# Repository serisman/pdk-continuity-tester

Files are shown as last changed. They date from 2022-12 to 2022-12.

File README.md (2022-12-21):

# pdk-continuity-tester
A simple standalone continuity tester, based on the ultra-inexpensive (~$0.03) Padauk microcontroller and a piezo buzzer.
- Turns on a Piezo Buzzer when there is continuity detected between the Probe pin and GND.
- Uses the Comparator to test for continuity (i.e. Reference(+) > Probe(-)).
- Goes to sleep after a short duration of inactivity to save battery power (< 0.5 uA).
- Optional LED indicates device is powered on and not sleeping.

This is a port of, and based on an original project for the ATtiny85(V) by David Johnson-Davies:
- http://www.technoblogy.com/show?1YON
- https://github.com/technoblogy/continuity-tester

### Links
- [Firmware](firmware/)
- [PCB](pcb-s08/)

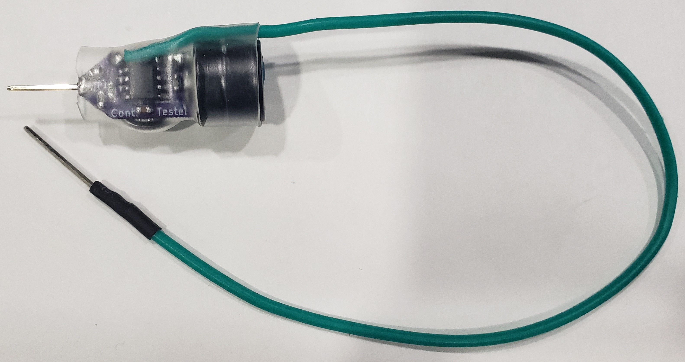
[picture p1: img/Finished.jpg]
Finished

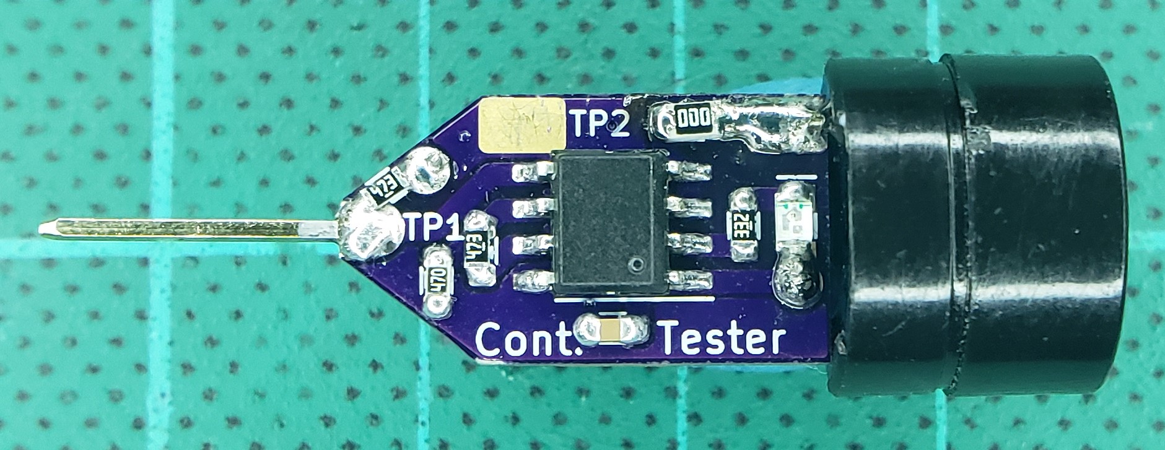
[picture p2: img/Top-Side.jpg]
Top Side

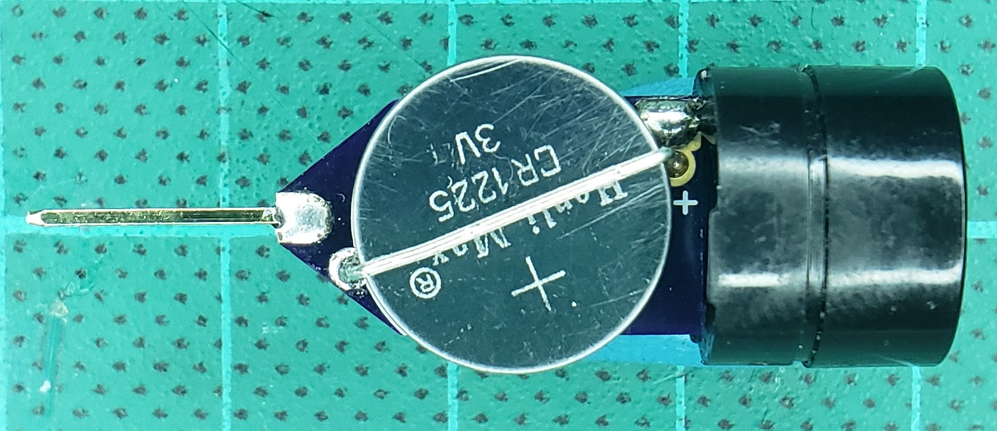
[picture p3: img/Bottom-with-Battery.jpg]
Bottom Side


### Hardware Circuit

##### Schematic
(for 8-pin PFS154, PFS173, PMS150C/PMS15A, PMS152, PMS154C, PMS171B)
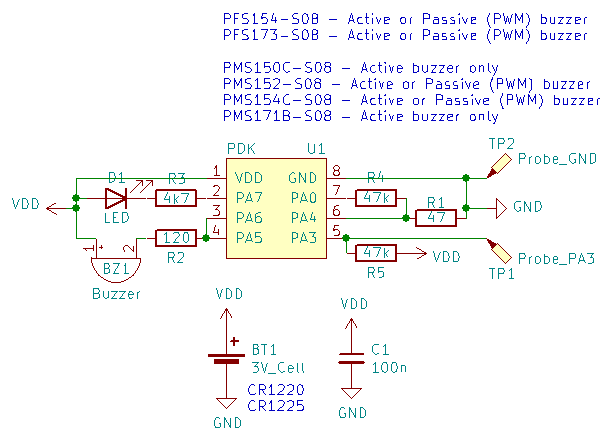
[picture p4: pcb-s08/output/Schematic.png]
Schematic


**Probe/Reference**:

One lead of the Probe is connected to one of the Comparator (-) pins, and the other lead is connected to GND. 
- The Probe lead is placed on the PA3 pin (Port A, Bit 3).

The Reference uses the Comparator (+) pin, with a 47 ohm resistor to GND.
- The Reference is placed on the PA4 pin (Port A, Bit 4). 

**Buzzer**:

The Buzzer is placed on the PA5 pin (Port A, Bit 5).  It is also connected to the PA6 pin, but the current firmware doesn't use this (yet).

For devices with an 11-bit PWM (i.e. PFS154, PFS173, PMS152, PMS154C), PA5 is also one of the PWM pins, enabling PWM control of the Buzzer's frequency using a Passive buzzer.

For other devices (i.e. PMS150C/PMS15A, PMS171B), the Buzzer can only be turned on/off and an Active buzzer is required.

In either case the Buzzer is used with a current sink configuration.

This means that one side of the Buzzer is connected to VDD, and the other is connected (through a current limiting resistor) to the digital pin of the IC.
- To enable the Buzzer (Passive / PWM), it is driven with an inverted 50% duty cycle at approx 2kHz.
- To enable the Buzzer (Active), it is driven LOW, meaning current will flow.
- To disable the Buzzer, it is floated HIGH, meaning no current will flow.

**LED**:

The LED is placed on the PA7 pin (Port A, Bit 7) with a current sink configuration.

This means the negative leg (or cathode) of the LED is connected to the digital pin of the IC, and the positive leg (or anode) of the LED is connected through a current limiting resistor to VDD.
- When the digital pin is LOW, current will flow through the LED and it will light up.
- When the digital pin is HIGH, no current will flow and the LED will turn off.

### Compatibility
This project is currently intended to be run (without modifications) on the PFS154, PFS173, PMS150C/PMS15A, PMS152, PMS154C, and PMS171B Padauk microcontrollers,
but it should be able to be modified to run on just about every currently known Padauk microcontroller that is supported by SDCC and the Easy PDK Programmer.
Some microcontrollers will require additional definitions in the [firmware/hal.h](firmware/hal.h) file,
and less common devices may require additional device specific include files (firmware/pdk/device/*.h) to be supplied.

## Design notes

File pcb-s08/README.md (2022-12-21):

# pcb-s08 ([pdk-continuity-tester](https://github.com/serisman/pdk-continuity-tester/))

### Schematic
(for 8-pin PFS154, PFS173, PMS150C, PMS15A, PMS152, PMS154C, PMS171B)
Schematic

### PCB

This PCB design was created with KiCad, and has been [shared on OSHPARK](https://oshpark.com/shared_projects/1CFwpMAd).
There are also gerber files available in the [output/gerber/](output/gerber/) directory, or [gerber.zip](output/gerber.zip).

Attach a ~12mm Piezo Buzzer to the end. PMS150C, PMS15A, and PMS171B require an Active (on/off) buzzer.  PFS154, PFS173, PMS152, and PMS154C use a Passive (PWM) buzzer.

Attach a CR1225 (or CR1220, CR1025, CR927, etc...) to the bottom after soldering a wire to hold it (and act as the positive contact).

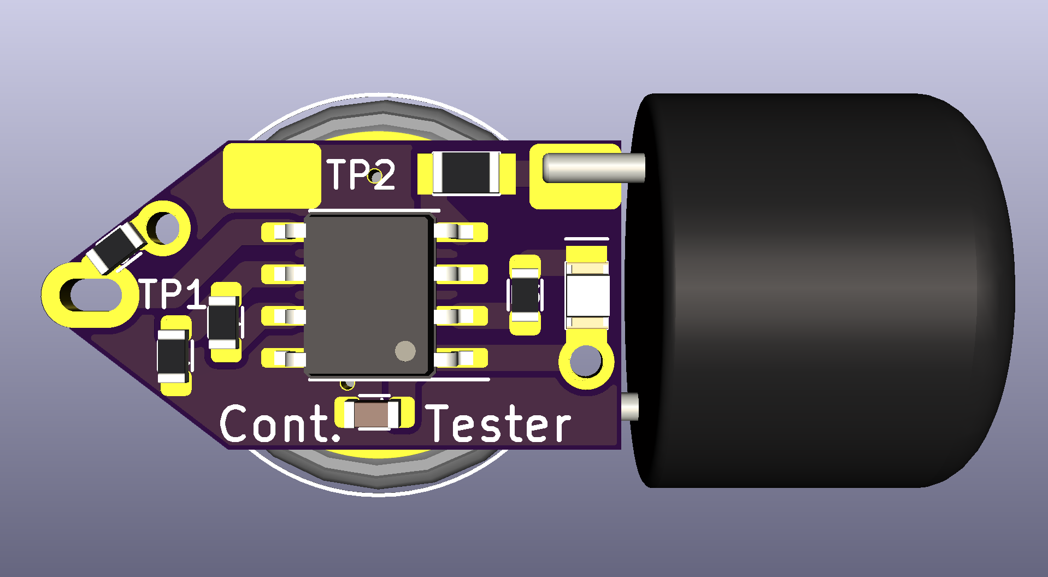
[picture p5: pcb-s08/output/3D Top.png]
3D Top

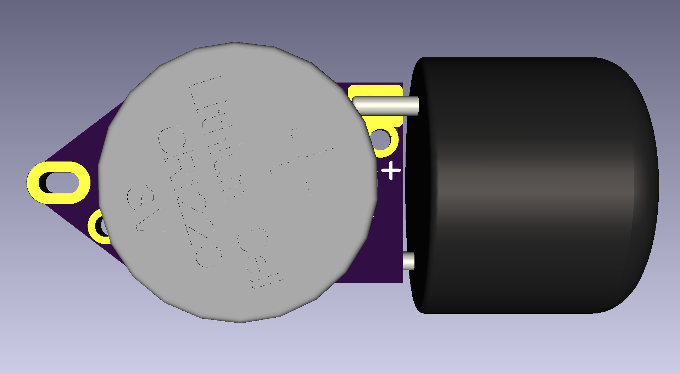
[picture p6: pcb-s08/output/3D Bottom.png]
3D Bottom


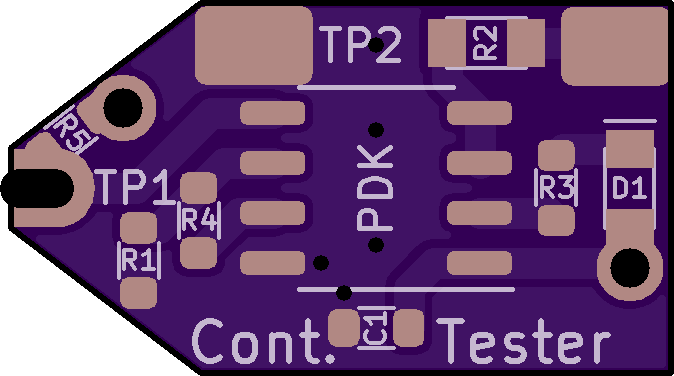
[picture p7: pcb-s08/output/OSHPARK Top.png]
PCB Top

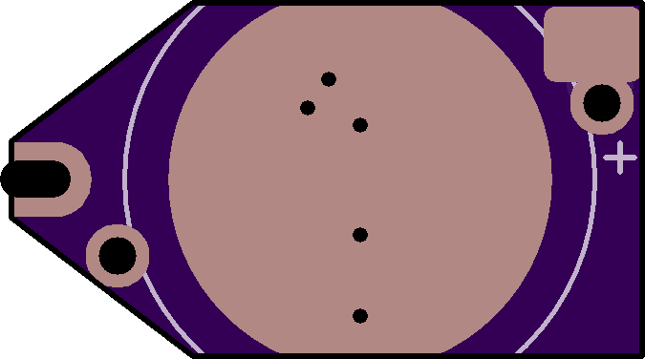
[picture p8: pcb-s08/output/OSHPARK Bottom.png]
PCB Bottom


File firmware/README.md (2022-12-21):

# firmware ([pdk-continuity-tester](https://github.com/serisman/pdk-continuity-tester/))

### Toolchain:
- The open-source [Small Device C Compiler (SDCC)](http://sdcc.sourceforge.net/)
  - Requires version 3.9.0 or newer - version 4.0.0+ preferred
- The open-source [Easy PDK Programmer](https://github.com/free-pdk/easy-pdk-programmer-software)
  - Requires version 1.3 or newer
- The open-source [pdk-includes](https://github.com/free-pdk/pdk-includes) repository
  - Integrated via local copy into the pdk/ directory
- The open-source [easy-pdk-includes](https://github.com/free-pdk/easy-pdk-includes) repository
  - Integrated via local copy into the easy-pdk/ directory
- Also requires 'make' and other common build tools

### Build Commands:
```
make clean
make build
make size (also calls build)
make program (also calls size which calls build)
```
> Note: These commands can be chained as well.  i.e. `make clean program`

### Customization:
Edit the variables at the top of the Makefile to:
- **DEVICE**: Use a different Padauk MCU (defaults to PFS154)
- **TARGET_VDD_MV**: Use a different voltage while calibrating the internal oscillator (IHRC) (defaults to 3000mV)

> Note: Both of these variables can be changed on the commandline as well.  i.e. `make DEVICE=PFS173 clean program` 

### Compatibility
This project is currently intended to be run (without modifications) on the PFS154, PFS173, PMS150C/PMS15A, PMS152, PMS154C, and PMS171B Padauk microcontrollers,
but it should be able to be modified to run on just about every currently known Padauk microcontroller that is supported by SDCC and the Easy PDK Programmer.
Some microcontrollers will require additional definitions in the [hal.h](hal.h) file,
and less common devices may require additional device specific include files (pdk/device/*.h) to be supplied.

### Build Stats
- Code Size: ~90-109 words (depending on the microcontroller)
- RAM usage: 2 bytes + stack

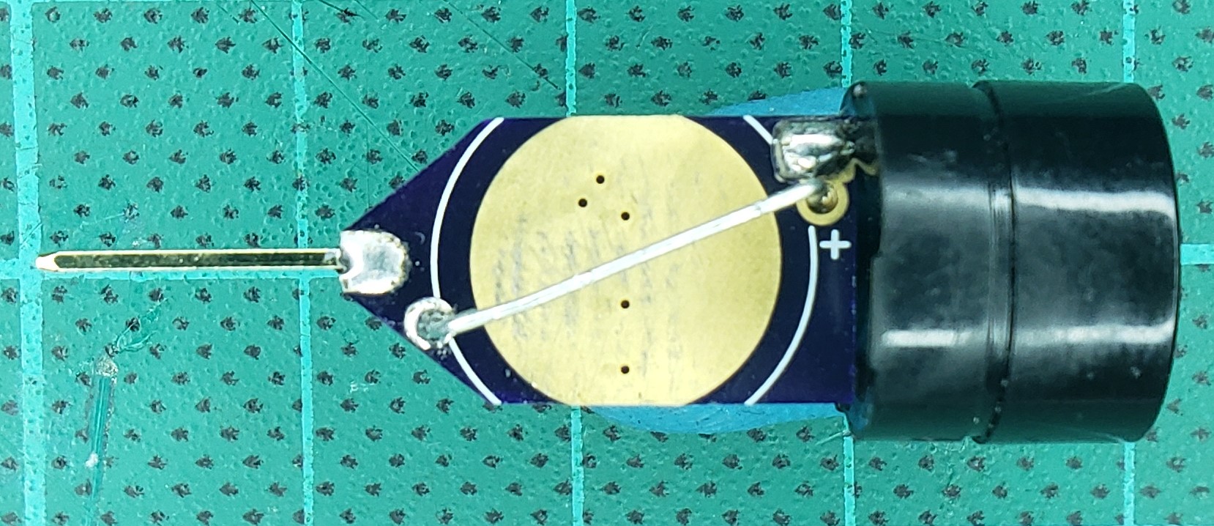
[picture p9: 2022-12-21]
img/Bottom-Side.jpg

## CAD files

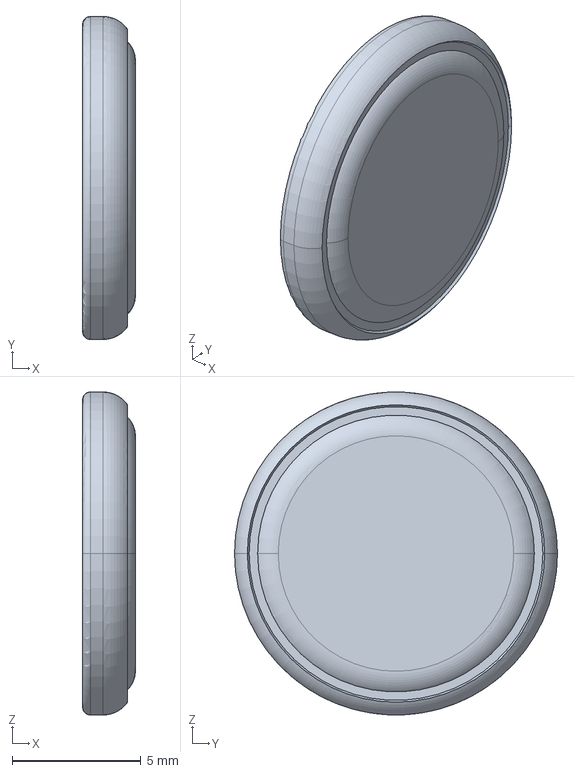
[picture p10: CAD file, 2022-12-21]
pcb-s08/modules/cr1220.step
2.05 x 12.6 x 12.5 mm

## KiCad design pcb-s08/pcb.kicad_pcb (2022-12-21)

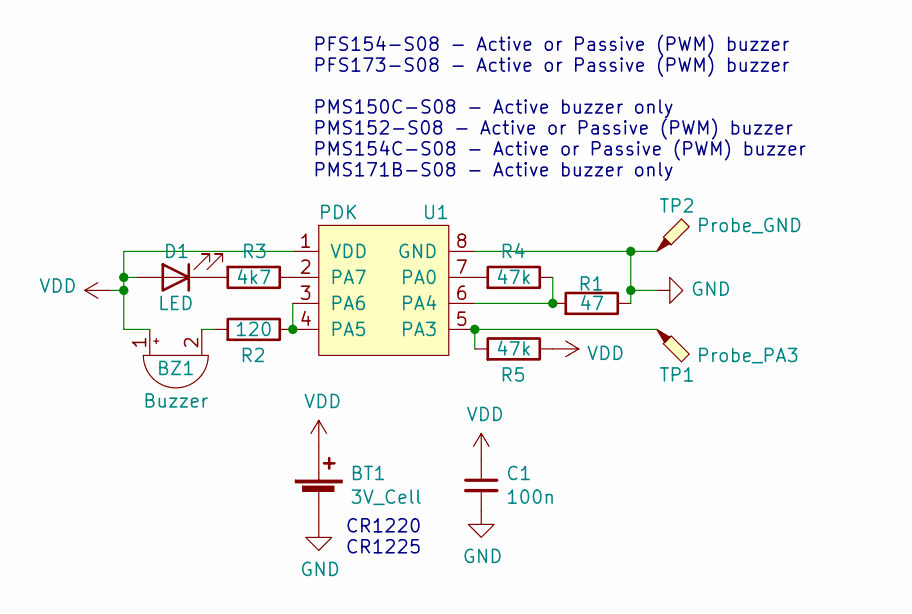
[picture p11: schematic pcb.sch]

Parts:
BT1: 3V_Cell; BatteryHolder_12mm
BZ1: Buzzer; Buzzer_12x9.5RM7.6
C1: 100n; C_0603
D1: LED; LED_0805
R1: 47; R_0603
R2: 120; R_0805
R3: 4k7; R_0603
R4, R5: 47k; R_0603
TP1: Probe_PA3; Pad_2.0x3.0mm
TP2: Probe_GND; Pad_2.0x3.0mm
U1: PDK; SOP-8_3.9x4.9mm_P1.27mm

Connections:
GND: BT1.2 (-), C1.2, R1.1, TP2.1, U1.8 (GND)
unnamed: BZ1.2 (+), R2.2
unnamed: D1.1 (K), R3.2
unnamed: R1.2, R4.1, U1.6 (PA4)
unnamed: R2.1, U1.3 (PA6), U1.4 (PA5)
unnamed: R3.1, U1.2 (PA7)
unnamed: R4.2, U1.7 (PA0)
unnamed: R5.2, TP1.1, U1.5 (PA3)
VDD: BT1.1 (+), BZ1.1 (-), C1.1, D1.2 (A), R5.1, U1.1 (VDD)

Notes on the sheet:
PFS154-S08 - Active or Passive (PWM) buzzer PFS173-S08 - Active or Passive (PWM) buzzer PMS150C-S08 - Active buzzer only PMS152-S08 - Active or Passive (PWM) buzzer PMS154C-S08 - Active or Passive (PWM) buzzer PMS171B-S08 - Active buzzer only
CR1220 CR1225

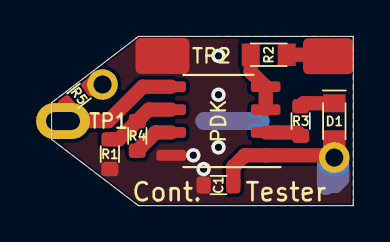
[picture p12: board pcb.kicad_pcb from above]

Board: 2 copper layers, 16.8 x 9.4 mm, 12 parts (1 on the bottom side), 9 nets.

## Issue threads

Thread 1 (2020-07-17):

Not working on PMS150C

kaweksl, 2020-07-17:
I made pcb , replaced buzzer with led since i don't have buzzers without generator
And it doesn't work,
tested also with PMS150C-S08 on breadboard and it doesn't work.
I have tested with PFS154 on breadboard and it works.

Status led is always On, after applying power there is something on buzzer for little time, but after that silence.

You have it working on PMS150C ?

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

serisman, 2020-07-17:
No, I haven't actually tested this on the PMS150C yet.  I will dig through the code and see if I can find what might be wrong.

serisman, 2020-07-17:
Well there was a typo in hal.h on line 20 that meant the wrong defines were used.  I'll push up a fix.  Maybe it was that simple?

serisman, 2020-07-17:
Ok, I can confirm that it is working properly on a 6-pin PMS150C (after the fix on line 20 of hal.h).

The only difference I found so far, is that the buzzer is operating at a much higher pitch.  I'll have to dig into the PWM values again.

kaweksl, 2020-07-17:
> Wow... you built that PCB pretty fast! I just designed the board this morning.
Design is small, uses mostly 1 layer, for that i have fast method. Photosensitive film + DLP 3D printer, 10 min. work + 1h waiting,

> The only difference I found so far, is that the buzzer is operating at a much higher pitch (about 8 kHz instead of 2 kHz). I'll have to dig into the PWM values again.

Almost works :)
Looks like pwm freq is ~8kHz but duty cycle is minimum (1 timers cycle ?)

kaweksl, 2020-07-17:
Hmm also it turns off even if probe is constantly shorted to ground.
I don't see 8kHz with 50% duty either.
Maybe pin change wakes up uC but comparator is not detecting anything and uC goes to sleep again ?.

serisman, 2020-07-17:
> Hmm also it turns off even if probe is constantly shorted to ground.
> I don't see 8kHz with 50% duty either.
> Maybe pin change wakes up uC but comparator is not detecting anything and uC goes to sleep again ?.

What voltage are you using?  I am noticing something similar on my PFS173 with anything over about 3.3V.  But, it seems correct at 3ish V.

kaweksl, 2020-07-17:
Powered with bench psu, now also tried with cr2032, same thing

serisman, 2020-07-17:
I just pushed some new code that fixes the PWM issues.  Can you give that a try?

Which IC are you currently testing with?

kaweksl, 2020-07-17:
PMS150C-u6

serisman, 2020-07-17:
Ok, weird.  I am not seeing that issue.

I just tested my PFS154 and PMW150C-U06, and they both work fine with any voltage from about 2 up to about 5.  I can hold the probes together and it will stay on until shortly after I separate them.

I do still have a weird issue with my PFS173 where it isn't working over about 3.3V, but seems to work fine between 2 up to about 3.2.  Maybe it is a bad IC, or maybe I'll have to dig through the datasheet more tomorrow to see if there is anything different about it.

FYI... signing off for the night (2:40 AM here).

kaweksl, 2020-07-17:
Shouldn't we calibrate bandgap ?

serisman, 2020-07-17:
> Shouldn't we calibrate bandgap ?

Maybe, but I don't think this actually uses the bandgap.

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

Ok, weird.  I'll have to do some additional testing with different chips myself.

> EDIT:
> Ok don't need to calibrate BG because we don't use it, maybe we should ?

Maybe.  How do you envision using it?

> I think pull-ups differ from chip to chip very much, as they are weak pmos, not resistors

Interesting.  Maybe we should try with external pull ups then.  According to the original article ~50k (i.e. 47k) would be a good value to try.

serisman, 2020-07-17:
I just tried using external 47k resistors on the Reference and Probe pins (Comp+ and Comp-), after commenting out the PAHP lines in the source code.  That seems to have fixed the weirdness I was seeing with the PFS173.

The downsides are two additional components, but more importantly, the idle power consumption increased dramatically because we have no way of turning off the external pull-up on the Reference pin (so there is always a 47k load).  I measured an idle power consumption increase from around 0.2 (+/- .1) uA up to 40-100 uA (depending on VDD).  That means a few weeks to months of idle time instead of many years.

I'll try some more tests later on when I have more free time.  Maybe higher value resistors would work just as well, and cause less idle power consumption.

serisman, 2020-07-17:
Another thought, although untested... we might be able to re-arrange the circuit a bit to pull-up the Reference and Probe lines to the 'power' LED, instead of pulling them up to VDD.  That way, no current would flow when the LED/MCU is off.  This would require changing the LED to be active high (source) instead of active low (sink).  Might still need an internal pull-up on Probe to still allow wake-up from sleep.  I'll have to think about this more.

serisman, 2020-07-17:
Did some more research and thinking on the subject, and have the additional observations:

1. The Padauk datasheets list a Comparator Offset of +/- 10-20 mV.  So there can be a fairly big difference between ICs.

2. The Padauk datasheets specify a pull-high resistance of approx 200k -> 600k (in the 3.3v -> 2v range) for the PFS154 and PMS150C chips, but only 150k -> 400k for the PFS173.  Either way, this is way higher than the ATtiny85's 20k - 50k.

3. The original circuit was build around a 50 ohm / ~50k ohm voltage divider for the reference, which means about 5mV at 5v.  We are using higher pull-ups and lower voltage, say 200k ohm and 3v, which is only 1mV reference.  Not sure how that interacts with the Comparator Offset that may be significantly more than our reference voltage.  We could increase the 50 ohm resistor to compensate, but that would mean we would trigger on higher resistances as well.  Or, we could decrease the pull-up resistor, but then we have to solve the idle power consumption issue.

kaweksl, 2020-07-18:
Sadly PA5 is open drain only :/ , Maybe it would be possible to make permanent pull-up on reference pin and switchable low resistor ?.
Or maybe swap PA6 and PA5
external pull-up on probe shouldn't take power

serisman, 2020-07-18:
> Making externally switchable pull-up might work but sadly PA5 is open drain only, and can source current only thru its pull-up :/

Yeah, I was thinking of the PFS154/PFS173 when I was thinking about that, where the LED is on PA6.  But, I agree, that won't work on the PMS150C where the LED is on PA5.

>, Maybe it would be possible to make permanent pull-up on reference pin and switchable low resistor ?.

Maybe, not sure at the moment.

> Or maybe swap PA6 and PA5. I'm not sure if PA5 have wake-up.

We can't really swap PA6/PA5, at least if we want 6-pin compatibility.  The reference has to be on the COMP+ pin which is PA4.  The probe has to be on a COMP- pin, which means PA3 for the PFS1xx, leaving only PA5 for the Buzzer which needs PWM.  That only leaves the PA6 for the LED.  For the PMS150C, the only available PWM is PA3, meaning PA6 has to be probe, and that only leaves PA5 for the LED.

> External pull-up on probe shouldn't take power while not operating.

Yeah, the probe doesn't matter.  The issue is with the Reference because it has the voltage divider that always consumes power unless you can remove one side from the equation.

serisman, 2020-07-18:
Ok, another option...

We can use the internal voltage reference, instead of creating our own.

Using GPCS, we can set VintR to a minimum of 1/32 * VDD, which means ~94 mV @ 3v.  This frees up the COMP+ pin (PA4) for other uses as well, and may mean we could now have a consistent set of pins across all devices.

To maintain a 50 ohm threshold/sensitivity, we would install an external 1.5k pull-up resistor on the probe pin, instead of using the internal pull-up.

Doing it this way solves the comparator offset/variance issues as well as the idle power consumption issues, but does have a downside that we have increased the current that passes through the probe to about ~1.875 mA.

Since most multimeters use around 1mA, it might be better to increase the sensitivity up to 100 ohm which decreases the current down to ~0.9375mA.

So, not as good as the 50 ohm / 0.1 uA of the original design, but at least as good as most multimeters.

serisman, 2022-12-21:
It's only been 2 1/2 years, but I finally picked this project back up and made a decision on how to fix the issue caused by the weak internal pull-up resistors.

After re-considering all the options, I felt that external pull-up resistors was the best of the available options.  In order to keep the low power consumption when sleeping, this means connecting one of them to an output pin (instead of directly to VDD).  This allows us to switch it off before entering sleep mode, thereby eliminating the constant drain.  This required an extra pin than the 6-pin ICs had available, so I just consolidated everything to a new single 8-pin design.

The old code/schematics/pcbs are still in a branch (old-vesion), but I don't intend to touch them further.

Closed 2022-12-21.

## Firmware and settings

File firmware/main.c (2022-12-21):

/*
  pdk-continuity-tester

  Copyright (C) 2020  serisman  <github@serisman.com>
  Based on an original project by David Johnson-Davies (http://www.technoblogy.com/show?1YON)

  Turns on a Piezo Buzzer when there is continuity detected between the Probe pin and GND.
  Uses the Comparator to test for continuity (i.e. Reference(+) > Probe(-)).
  Goes to sleep after a short duration of inactivity to save battery power.
  Optional LED indicates device is powered on and not sleeping.

  ----------------------------------------------------------------------
  CC BY 4.0
  Licensed under a Creative Commons Attribution 4.0 International license:
  http://creativecommons.org/licenses/by/4.0/
*/

#include <stdint.h>
#include <pdk/device.h>
#include <easy-pdk/calibrate.h>
#include "hal.h"

uint16_t idle_counter = 0x0FFF;

// Main program
void main() {

  // Disable wake-up on un-used pins to save power
  PADIER = 0x00;
#if defined(PBDIER)
  PBDIER = 0x00;
#endif
#if defined(PCDIER)
  PCDIER = 0x00;
#endif

  // Initialize Buzzer, LED, Probe, and Reference Pins
  PAC = (uint8_t)((1<<LED_BIT)|(1<<BUZZER_BIT)|(1<<PULL_REF_HI_BIT));  // Set Buzzer and LED Pins as output
  PAPH = 0x00;
  PA |= (1<<PULL_REF_HI_BIT);           // Enable pull-up on Reference Pin
  ledOn();
  buzzerInitPWM();

  // Setup/enable the Comparator for continuity testing (i.e. Reference(+) > Probe(-))
  GPCC = (uint8_t)(GPCC_COMP_ENABLE | COMP_MINUS | GPCC_COMP_PLUS_PA4);

  // Main processing loop
  while (1) {

    if ((GPCC & GPCC_COMP_RESULT_POSITIVE) == GPCC_COMP_RESULT_POSITIVE) {
      // Continuity found, turn Buzzer on, reset idle counter
      buzzerOn();
      idle_counter = 0x0FFF;
    } else {
      // No continuity, turn Buzzer off, go to sleep after a short delay
      buzzerOff();
      idle_counter--;
      if (idle_counter == 0) {
        ledOff();
        GPCC &= ~(GPCC_COMP_ENABLE);          // Disable Comparator to save power
        PA &= ~(1<<PULL_REF_HI_BIT);           // Turn off pull-up on Reference Pin to save power
        PADIER = (1<<PROBE_BIT);              // Enable wake-up on Probe Pin
        MISC = (MISC_FAST_WAKEUP_ENABLE | MISC_LVR_DISABLE); // Disable LVR to save power

        __stopsys();                          // Go to sleep

        // Carry on here when we wake up
        MISC = 0x00;                          // Re-enable LVR
        PADIER = 0x00;
        PA |= (1<<PULL_REF_HI_BIT);           // Re-enable pull-up on Reference Pin
        GPCC |= (GPCC_COMP_ENABLE);           // Re-enable Comparator
        ledOn();
      }
    }
  }
}

// Startup code - Setup/calibrate system clock
unsigned char _sdcc_external_startup(void) {

  // Set FUSE:
  // - 1.8v LVR (if available)
  // - Normal IO Drive (if available)
  // - Fast Bootup (if available)
  // - Security Off
#if defined(FUSE_LVR_1V8) && defined(FUSE_IO_DRV_NORMAL) && defined(FUSE_BOOTUP_FAST)
  PDK_SET_FUSE(FUSE_BOOTUP_FAST | FUSE_IO_DRV_NORMAL | FUSE_LVR_1V8 | FUSE_SECURITY_OFF);
#elif defined(FUSE_LVR_1V8)
  PDK_SET_FUSE(FUSE_LVR_1V8 | FUSE_SECURITY_OFF);
#elif defined(FUSE_IO_DRV_NORMAL) && defined(FUSE_BOOTUP_FAST)
  PDK_SET_FUSE(FUSE_BOOTUP_FAST | FUSE_IO_DRV_NORMAL | FUSE_SECURITY_OFF);
#elif defined(FUSE_BOOTUP_FAST)
  PDK_SET_FUSE(FUSE_BOOTUP_FAST | FUSE_SECURITY_OFF);
#else
  PDK_SET_FUSE(FUSE_SECURITY_OFF);
#endif

  // Set LVR:
  // - 1.8v (if available)
  // - otherwise 2.0v (if available)
#if defined(MISCLVR_1V8)
  MISCLVR = (uint8_t) MISCLVR_1V8;
#elif defined(MISCLVR_2V)
  MISCLVR = (uint8_t) MISCLVR_2V;
#endif

  // Initialize the system clock (CLKMD register) for 1MHz operation (IHRC/16)
  PDK_SET_SYSCLOCK(SYSCLOCK_IHRC_1MHZ);

  // Insert placeholder code to tell EasyPdkProg to calibrate the IHRC internal oscillator for 1MHz operation.
  EASY_PDK_CALIBRATE_IHRC(1000000, TARGET_VDD_MV);

  return 0;   // Return 0 to inform SDCC to continue with normal initialization.
}

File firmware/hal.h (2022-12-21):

/*
  hal.h - Device specific definitions and helper methods for the pdk-continuity-tester project.

  ----------------------------------------------------------------------
  Copyright (C) 2020  serisman  <github@serisman.com>

  CC BY 4.0
  Licensed under a Creative Commons Attribution 4.0 International license:
  http://creativecommons.org/licenses/by/4.0/
*/

#ifndef __HAL_H__
#define __HAL_H__

#if !defined(PFS154) && !defined(PFS173) && !defined(PMS150C) && !defined(PMS15A) && !defined(PMS152) && !defined(PMS154C) && !defined(PMS171B)
  #error "Device not currently supported!"
#endif

// Define which pins to use
#define PULL_REF_HI_BIT   0     // 47k Reference pull-up resistor is on PA0 (Port A, Bit 0)
#define REFERENCE_BIT     4     // Reference is on PA4 (Port A, Bit 4), which is also Comp+
#define PROBE_BIT         3     // Probe is on PA3 (Port A, Bit 3), which is also Comp-
#define BUZZER_BIT        5     // Buzzer is placed on the PA5 pin (Port A, Bit 5), which is also PWM2 (Note: PWM not available on PMS150C,PMS15A,PMS171B)
//#define BUZZER_BIT      6     // Buzzer is placed on the PA6 pin (Port A, Bit 6)
#define LED_BIT           7     // LED is placed on the PA7 pin (Port A, Bit 7)

#define COMP_MINUS        GPCC_COMP_MINUS_PA3

// Helpers to initialize Buzzer PWM and turn Buzzer on/off
#if defined(PMS150C) || defined(PMS15A) || defined(PMS171B)
  inline void buzzerInitPWM() { }
  #define buzzerOn()          PA &= ~(1 << BUZZER_BIT)
  #define buzzerOff()         PA |= (1 << BUZZER_BIT)
  #warning Remember to use an Active Buzzer with PMS150C,PMS15A,PMS171B
#else
  #if defined(PWMG2CUBL)            // Full 11-bit PWM:   PFS154,PMS154C
    inline void buzzerInitPWM() {
      PWMG2CUBL = 0xC0;             // Set the PWM upper bound (255+1)
      PWMG2CUBH = 0x3F;
      PWMG2DTL = 0xE0;              // Set the PWM duty value (127 + 0.5 + 0.5) = 50%
      PWMG2DTH = 0x1F;
      PWMG2S = (uint8_t)(PWMG2S_SCALE_DIV32); // Set the PWM frequency to ~1.953 kHz
    }
    #define buzzerOn()          PWMG2C = (uint8_t)(PWMG2C_ENABLE | PWMG2C_INVERT_OUT | PWMG2C_OUT_PA5 | PWMG2C_CLK_IHRC)
    #define buzzerOff()         PWMG2C = 0x00; PA |= (1 << BUZZER_BIT)
  #elif defined(PWMGCUBL)           // Basic 11-bit PWM:  PFS173,PMS152
    inline void buzzerInitPWM() {
      PWMGCUBL = 0xC0;              // Set the PWM upper bound (255+1)
      PWMGCUBH = 0x3F;
      PWMG2DTL = 0xE0;              // Set the PWM duty value (127 + 0.5 + 0.5) = 50%
      PWMG2DTH = 0x1F;
      PWMGCLK = (uint8_t)(PWMGCLK_PWMG_ENABLE | PWMGCLK_CLK_IHRC | PWMGCLK_PRESCALE_DIV32); // Set the PWM frequency to ~1.953 kHz
    }
    #define buzzerOn()          PWMG2C = (uint8_t)(PWMG2C_INVERT_OUT | PWMG2C_OUT_PWMG2 | PWMG2C_OUT_PA5)
    #define buzzerOff()         PWMG2C = 0x00; PA |= (1 << BUZZER_BIT)
  #endif
#endif

// LED is active low (current sink), so define helpers for better readability
#define ledOn()             PA &= ~(1 << LED_BIT)
#define ledOff()            PA |= (1 << LED_BIT)

#endif //__HAL_H__

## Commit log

2020-07-16 Add schematic for PMS150C-U06
2020-07-16 Add PCB for PMS150C-U06
    [pcb-pms150c-B_Cu.gbr, pcb-pms150c-B_Mask.gbr, pcb-pms150c-B_Paste.gbr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]
2020-07-16 Update Schematic
2020-07-16 Rename pcb files
    [pcb-B_Cu.gbr, pcb-B_Mask.gbr, pcb-B_Paste.gbr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]
2020-07-16 Add Schematic for 8-pin PFS154, PFS173, PMS152, PMS154C
    [pcb.sch]
2020-07-16 Update 8-pin Schematic and README.md
    [pcb.sch]
2020-07-16 Add Package
    [pcb.sch]
2020-07-17 Move PCB section out of main README and into sub-folder's README
2020-07-17 Fix typo related to PMS150C
    [hal.h]
2020-07-17 Fix typo in a comment
    [hal.h]
2020-07-17 Fix PWM code
2020-07-19 Pull in upstream fixes
    [hal.h, main.c]
2020-07-21 Update Schematics
2022-12-21 New version (using 8-pin IC with external pull-up resistors).
    [cr1220.step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]
